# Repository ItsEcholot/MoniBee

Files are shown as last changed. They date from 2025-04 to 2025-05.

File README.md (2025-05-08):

# MoniBee 🐝

A custom ZigBee device designed for adding home automations to your monitor / workstation setup based on the ESP32-C6 MCU.

## Features

- CEC Control via HDMI:
  - Switch monitor input sources
  - Control power state
  - Adjust backlight brightness
- Ambient Light Sensor:
  - [VEML7700](https://www.vishay.com/docs/84286/veml7700.pdf) is used for accurate ambient light measurements
- IR Transmitter (NEC Protocol):
  - Supports sending custom commands over ZigBee for controlling various devices (Speakers, KVM switches, ...)
- ZigBee Communication:
  - [External converter](z2m_external_converter.js) for [Zigbee2Mqtt](https://www.zigbee2mqtt.io)
    - Allows for integration into [HomeAssistant](https://www.home-assistant.io) for easy automation
  - Low power usage (average of 1mah, could be further reduced with less aggressive CEC polling & ambient light measurements)

## ZigBee endpoints & clusters
- Internal temperature (ESP32-C6 sensor), only accurate if chip is hot:
  - Endpoint: `10`
  - Clusters: Basic, identify cluster and temperature measurement (HA profile) as server side. Identify cluster as client side.
- Ambient light (VEML7700):
  - Endpoint: `11`
  - Clusters: Basic, identify and illuminance clusters (HA profile) as server side.
- Monitor DDC:
  - Endpoint: `12`
  - Clusters: Basic, identify and custom cluster for ddc control with the following attributes as server side:
    - `0x0000 R/W, Reporting, 16bit enum`: Input select (see [ddc.h](src/ddc.h) for enum values)
    - `0x0001 R/W, Reporting, 16bit unsigned`: Brightness (in percent)
    - `0x0002 R/W, Reporting, 8bit enum`: Power mode
- IR Emitter:
  - Endpoint: `13`
  - Clusters: Basic, identify and custom cluster for ir commands without attributes but a **custom command** as server side:
    - `0x0000, payload: 4 bytes, bytes 1 & 2: NEC address (little endian), bytes 3 & 4: NEC command (little endian)`: IR command

## Board
The Tenstar Robot ESP32-C6 Supermini ([AliExpress link](https://www.aliexpress.com/item/1005006406538478.html)) was used because of its small size and the inclusion of an RGB LED to display the current system status.

## Pinout
| Pin | Usage |
| --- | ----- |
| 0 | I2C SDA (HDMI CEC [I recommend using a logic level shifter, HDMI uses 5v] & VEML7700) |
| 1 | I2C SCL (HDMI CEC [I recommend using a logic level shifter, HDMI uses 5v] & VEML7700) |
| 6 | IR LED Cathode |
| 7 | IR LED Anode (**use a properly sized resistor!**) |
| 8 (Built in RGB LED) | WS2812 LED to show current ZigBee Status (green = reset successful, red = connecting, off = ready) |
| 9 (Boot button) | Reset / Re-pair ZigBee |
| 15 (Built in LED) | on = awake, off = light sleep |

## 3D Printed Case
To house all the electronics I have designed a simple 3d printable case. The files for which can be found in the project root. See pictures & screenshots below for some impressions.

## Screenshots & Pictures
soldered monibee without case
monibee mounted to back of monitor with 3d printed case
monibee 3d printed mounting tray
zigbee2-mqtt screenshot
homeassistant screenshot

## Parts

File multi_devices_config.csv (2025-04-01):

id | installcode | mac_address | channel_mask_page0 | manufacturer_name | manufacturer_code
1 | BDE2AF63810BCBC503AC | E4B063FFFE420820 | 0x00008000 | Echolot | 0xec01
# last 4 digits -> CRC16/X25 swap the two bytes

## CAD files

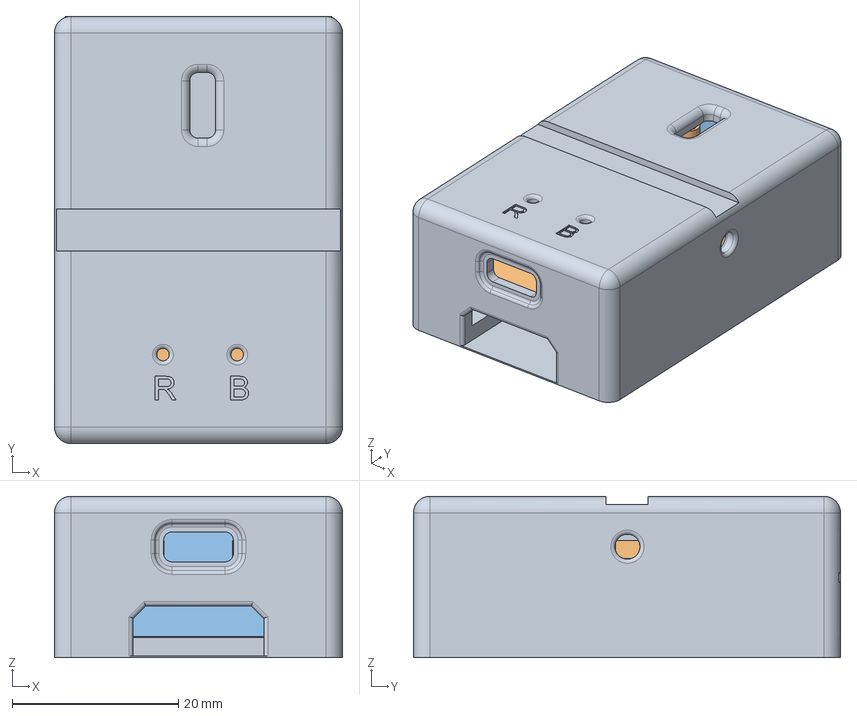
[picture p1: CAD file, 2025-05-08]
MoniBee Case v17.step
34.7 x 51.4 x 19.4 mm
MoniBeeHardwareVEML7700
MoniBeeHardwareESP32
MoniBeeHardwareHDMI

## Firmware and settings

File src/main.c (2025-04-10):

#include <freertos/FreeRTOS.h>
#include <freertos/task.h>
#include <esp_pm.h>
#include <esp_private/esp_clk.h>
#include <esp_sleep.h>
#include <nvs_flash.h>
#include <esp_zigbee_core.h>
#include <driver/i2c_master.h>
#include <soc/usb_serial_jtag_reg.h>

#include "led.h"
#include "zigbee.h"
#include "button_boot.h"
#include "internal_temperature.h"

static bool has_usb_connection(void)
{
  uint32_t *frame_num_val = (uint32_t *)USB_SERIAL_JTAG_FRAM_NUM_REG;
  uint32_t first_read_val = *frame_num_val;
  vTaskDelay(100 / portTICK_PERIOD_MS);
  return *frame_num_val != first_read_val;
}

static esp_err_t init_power_save(void)
{
  esp_err_t rc = ESP_OK;
#ifdef CONFIG_PM_ENABLE
  int cur_cpu_freq_mhz = CONFIG_ESP_DEFAULT_CPU_FREQ_MHZ;
  esp_pm_config_t pm_config = {
      .max_freq_mhz = cur_cpu_freq_mhz,
      .min_freq_mhz = cur_cpu_freq_mhz,
#if CONFIG_FREERTOS_USE_TICKLESS_IDLE
      .light_sleep_enable = !has_usb_connection(),
#endif
  };
  rc = esp_pm_configure(&pm_config);
#endif
  return rc;
}

static esp_err_t init_i2s(void)
{
  i2c_master_bus_config_t bus_config = {
      .i2c_port = I2C_NUM_0,
      .clk_source = I2C_CLK_SRC_DEFAULT,
      .scl_io_num = GPIO_NUM_1,
      .sda_io_num = GPIO_NUM_0,
      .flags = {
          .allow_pd = true,
          .enable_internal_pullup = true,
      },
  };

  i2c_master_bus_handle_t bus_handle;
  return i2c_new_master_bus(&bus_config, &bus_handle);
}

void app_main()
{
  esp_zb_platform_config_t config = {
      .radio_config = {
          .radio_mode = ZB_RADIO_MODE_NATIVE,
      },
      .host_config = {
          .host_connection_mode = ZB_HOST_CONNECTION_MODE_NONE,
      },
  };
  ESP_ERROR_CHECK(nvs_flash_init());
  ESP_ERROR_CHECK(init_power_save());
  ESP_ERROR_CHECK(init_i2s());
  ESP_ERROR_CHECK(esp_zb_platform_config(&config));

  xTaskCreate(zigbee_task, "zigbee_task", 4096, NULL, 5, NULL);
  xTaskCreate(led_task, "led_task", 2048, NULL, 1, NULL);
  xTaskCreate(button_boot_task, "button_boot_task", 2048, NULL, 2, NULL);
}

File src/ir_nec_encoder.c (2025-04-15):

/*
 * SPDX-FileCopyrightText: 2021-2022 Espressif Systems (Shanghai) CO LTD
 *
 * SPDX-License-Identifier: Apache-2.0
 */

 #include "esp_check.h"
 #include "ir_nec_encoder.h"
 
 static const char *TAG = "nec_encoder";
 
 typedef struct {
     rmt_encoder_t base;           // the base "class", declares the standard encoder interface
     rmt_encoder_t *copy_encoder;  // use the copy_encoder to encode the leading and ending pulse
     rmt_encoder_t *bytes_encoder; // use the bytes_encoder to encode the address and command data
     rmt_symbol_word_t nec_leading_symbol; // NEC leading code with RMT representation
     rmt_symbol_word_t nec_ending_symbol;  // NEC ending code with RMT representation
     int state;
 } rmt_ir_nec_encoder_t;
 
 static size_t rmt_encode_ir_nec(rmt_encoder_t *encoder, rmt_channel_handle_t channel, const void *primary_data, size_t data_size, rmt_encode_state_t *ret_state)
 {
     rmt_ir_nec_encoder_t *nec_encoder = __containerof(encoder, rmt_ir_nec_encoder_t, base);
     rmt_encode_state_t session_state = RMT_ENCODING_RESET;
     rmt_encode_state_t state = RMT_ENCODING_RESET;
     size_t encoded_symbols = 0;
     ir_nec_scan_code_t *scan_code = (ir_nec_scan_code_t *)primary_data;
     rmt_encoder_handle_t copy_encoder = nec_encoder->copy_encoder;
     rmt_encoder_handle_t bytes_encoder = nec_encoder->bytes_encoder;
     switch (nec_encoder->state) {
     case 0: // send leading code
         encoded_symbols += copy_encoder->encode(copy_encoder, channel, &nec_encoder->nec_leading_symbol,
                                                 sizeof(rmt_symbol_word_t), &session_state);
         if (session_state & RMT_ENCODING_COMPLETE) {
             nec_encoder->state = 1; // we can only switch to next state when current encoder finished
         }
         if (session_state & RMT_ENCODING_MEM_FULL) {
             state |= RMT_ENCODING_MEM_FULL;
             goto out; // yield if there's no free space to put other encoding artifacts
         }
     // fall-through
     case 1: // send address
         encoded_symbols += bytes_encoder->encode(bytes_encoder, channel, &scan_code->address, sizeof(uint16_t), &session_state);
         if (session_state & RMT_ENCODING_COMPLETE) {
             nec_encoder->state = 2; // we can only switch to next state when current encoder finished
         }
         if (session_state & RMT_ENCODING_MEM_FULL) {
             state |= RMT_ENCODING_MEM_FULL;
             goto out; // yield if there's no free space to put other encoding artifacts
         }
     // fall-through
     case 2: // send command
         encoded_symbols += bytes_encoder->encode(bytes_encoder, channel, &scan_code->command, sizeof(uint16_t), &session_state);
         if (session_state & RMT_ENCODING_COMPLETE) {
             nec_encoder->state = 3; // we can only switch to next state when current encoder finished
         }
         if (session_state & RMT_ENCODING_MEM_FULL) {
             state |= RMT_ENCODING_MEM_FULL;
             goto out; // yield if there's no free space to put other encoding artifacts
         }
     // fall-through
     case 3: // send ending code
         encoded_symbols += copy_encoder->encode(copy_encoder, channel, &nec_encoder->nec_ending_symbol,
                                                 sizeof(rmt_symbol_word_t), &session_state);
         if (session_state & RMT_ENCODING_COMPLETE) {
             nec_encoder->state = RMT_ENCODING_RESET; // back to the initial encoding session
             state |= RMT_ENCODING_COMPLETE;
         }
         if (session_state & RMT_ENCODING_MEM_FULL) {
             state |= RMT_ENCODING_MEM_FULL;
             goto out; // yield if there's no free space to put other encoding artifacts
         }
     }
 out:
     *ret_state = state;
     return encoded_symbols;
 }
 
 static esp_err_t rmt_del_ir_nec_encoder(rmt_encoder_t *encoder)
 {
     rmt_ir_nec_encoder_t *nec_encoder = __containerof(encoder, rmt_ir_nec_encoder_t, base);
     rmt_del_encoder(nec_encoder->copy_encoder);
     rmt_del_encoder(nec_encoder->bytes_encoder);
     free(nec_encoder);
     return ESP_OK;
 }
 
 static esp_err_t rmt_ir_nec_encoder_reset(rmt_encoder_t *encoder)
 {
     rmt_ir_nec_encoder_t *nec_encoder = __containerof(encoder, rmt_ir_nec_encoder_t, base);
     rmt_encoder_reset(nec_encoder->copy_encoder);
     rmt_encoder_reset(nec_encoder->bytes_encoder);
     nec_encoder->state = RMT_ENCODING_RESET;
     return ESP_OK;
 }
 
 esp_err_t rmt_new_ir_nec_encoder(const ir_nec_encoder_config_t *config, rmt_encoder_handle_t *ret_encoder)
 {
     esp_err_t ret = ESP_OK;
     rmt_ir_nec_encoder_t *nec_encoder = NULL;
     ESP_GOTO_ON_FALSE(config && ret_encoder, ESP_ERR_INVALID_ARG, err, TAG, "invalid argument");
     nec_encoder = rmt_alloc_encoder_mem(sizeof(rmt_ir_nec_encoder_t));
     ESP_GOTO_ON_FALSE(nec_encoder, ESP_ERR_NO_MEM, err, TAG, "no mem for ir nec encoder");
     nec_encoder->base.encode = rmt_encode_ir_nec;
     nec_encoder->base.del = rmt_del_ir_nec_encoder;
     nec_encoder->base.reset = rmt_ir_nec_encoder_reset;
 
     rmt_copy_encoder_config_t copy_encoder_config = {};
     ESP_GOTO_ON_ERROR(rmt_new_copy_encoder(&copy_encoder_config, &nec_encoder->copy_encoder), err, TAG, "create copy encoder failed");
 
     // construct the leading code and ending code with RMT symbol format
     nec_encoder->nec_leading_symbol = (rmt_symbol_word_t) {
         .level0 = 1,
         .duration0 = 9000ULL * config->resolution / 1000000,
         .level1 = 0,
         .duration1 = 4500ULL * config->resolution / 1000000,
     };
     nec_encoder->nec_ending_symbol = (rmt_symbol_word_t) {
         .level0 = 1,
         .duration0 = 560 * config->resolution / 1000000,
         .level1 = 0,
         .duration1 = 0x7FFF,
     };
 
     rmt_bytes_encoder_config_t bytes_encoder_config = {
         .bit0 = {
             .level0 = 1,
             .duration0 = 560 * config->resolution / 1000000, // T0H=560us
             .level1 = 0,
             .duration1 = 560 * config->resolution / 1000000, // T0L=560us
         },
         .bit1 = {
             .level0 = 1,
             .duration0 = 560 * config->resolution / 1000000,  // T1H=560us
             .level1 = 0,
             .duration1 = 1690 * config->resolution / 1000000, // T1L=1690us
         },
     };
     ESP_GOTO_ON_ERROR(rmt_new_bytes_encoder(&bytes_encoder_config, &nec_encoder->bytes_encoder), err, TAG, "create bytes encoder failed");
 
     *ret_encoder = &nec_encoder->base;
     return ESP_OK;
 err:
     if (nec_encoder) {
         if (nec_encoder->bytes_encoder) {
             rmt_del_encoder(nec_encoder->bytes_encoder);
         }
         if (nec_encoder->copy_encoder) {
             rmt_del_encoder(nec_encoder->copy_encoder);
         }
         free(nec_encoder);
     }
     return ret;
 }

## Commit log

2025-03-30 Initial working ED version with internal temperature reporting
    [multi_devices_config.csv, partitions.csv]
2025-03-30 Add measurement delay to internal temperature task
2025-04-01 Enable ZigBee sleep
    [multi_devices_config.csv]
2025-04-02 Working tickless light sleep, internal temp sensor broken
    [partitions.csv]
2025-04-03 Fix internal temperature measurements without breaking light sleep & disable light sleep with USB attached
    [main.c, veml_7700.c]
2025-04-04 Read brightness value from VEML7700 sensor
2025-04-05 Cleanup internal temperature change handling
2025-04-09 Implement basic ddc querying & custom cluster and attribute for reporting current input
2025-04-12 Add display brightness attribute & fix ddc vcp reading
    [ddc.c]
2025-04-13 Add ddc power mode control
2025-04-13 Add external converter for zigbee2mqtt & switch to honoring coordinator reporting settings
2025-04-15 Show ZigBee connection state with RGB LED & wakup from light sleep on boot button press
2025-05-01 Prevent LightSleep during veml7700 ambient light measurements
    [veml_7700.c]
2025-05-08 Add 3d printeable case
    [MoniBee Case v17.step]
